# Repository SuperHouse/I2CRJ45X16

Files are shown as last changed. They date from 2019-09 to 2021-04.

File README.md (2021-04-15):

I2C to RJ45 Breakout (16 Port)
==============================
Copyright 2019-2021 SuperHouse Automation Pty Ltd  www.superhouse.tv  

24 RJ45 sockets connected to 64 I/O channels via I2C addressable
I/O controllers. Intended for use in building a home automation light
switch controller for connection to SuperHouse light switches.

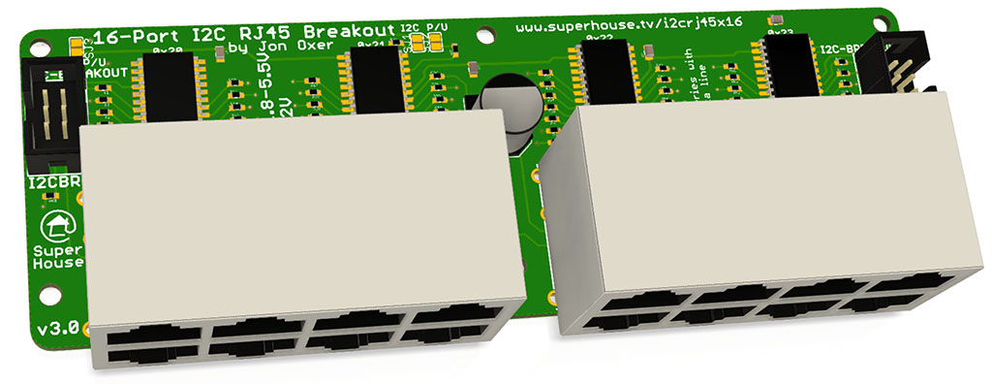
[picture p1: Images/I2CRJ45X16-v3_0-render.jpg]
I2C RJ45 Breakout PCB


Features:

 * 16 x RJ45 sockets for connection to light switches over Cat-5
 * I2C interface with interrupt output

This project has different versions:

 * 8-port version: https://github.com/superhouse/i2crj45x8
 * 16-port version: https://github.com/superhouse/i2crj45x16
 * 24-port version: https://github.com/superhouse/i2crj45x24
 * 24-port version with passthrough: https://github.com/superhouse/i2crj45x24pt

More information:

  http://www.superhouse.tv/i2crj45x16

INSTALLATION
------------
The design is saved as an EAGLE project. EAGLE PCB design software is
available from www.cadsoftusa.com free for non-commercial use. To use
this project download it and place the directory containing these files
into the "eagle" directory on your computer. Then open EAGLE and
navigate to the project.

CREDITS
-------
Designed by Jonathan Oxer jon@oxer.com.au

DISTRIBUTION
------------
The specific terms of distribution of this project are governed by the
license referenced below.

LICENSE
-------
Licensed under the TAPR Open Hardware License (www.tapr.org/OHL).
The "license" folder within this repository also contains a copy of
this license in plain text format.

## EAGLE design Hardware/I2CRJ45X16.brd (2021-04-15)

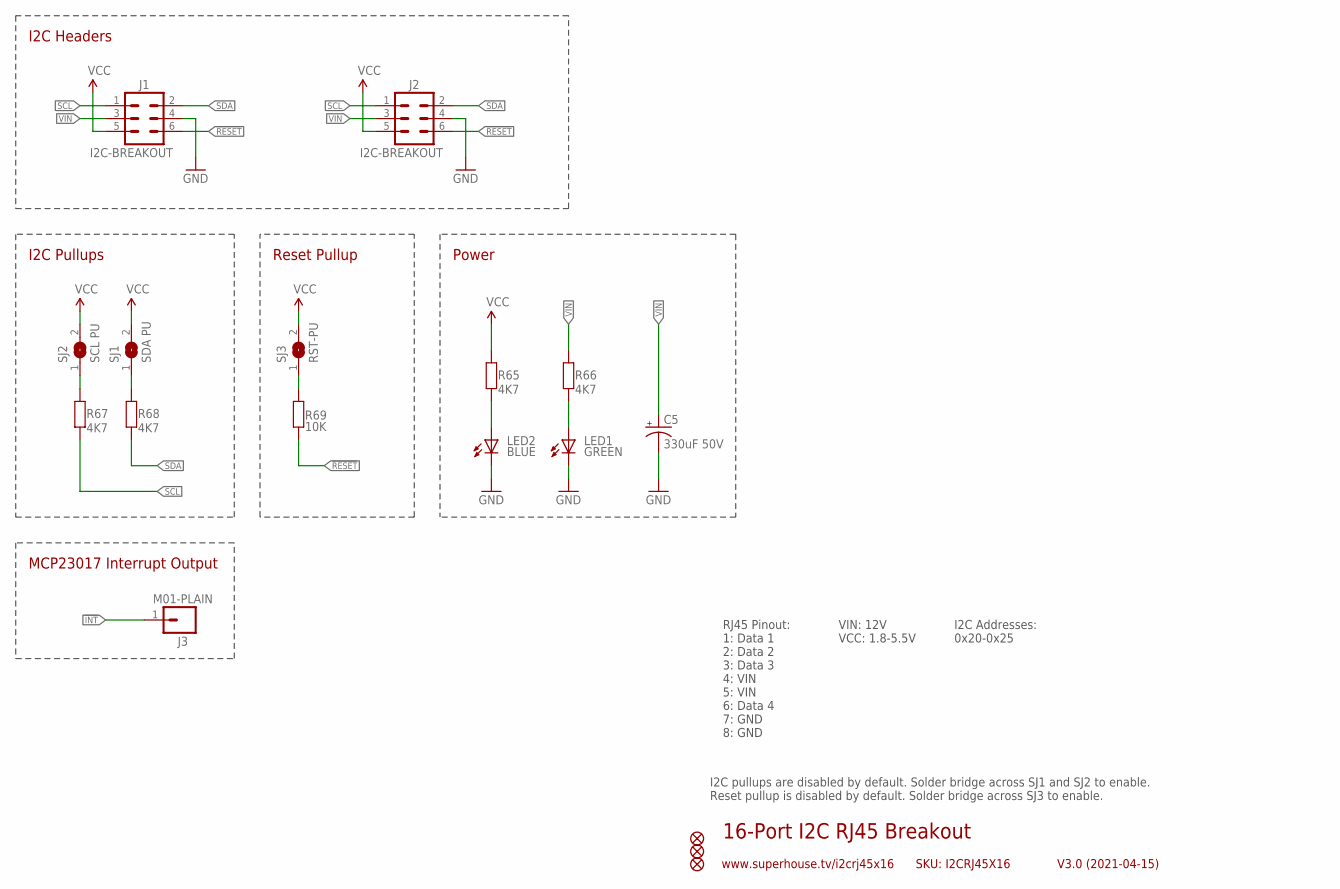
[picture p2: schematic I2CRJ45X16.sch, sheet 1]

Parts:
C5: 330uF 50V; PANASONIC_G
FID1, FID2, FID3: FIDUCIAL1X2.5; FIDUCIAL-1X2.5
J1, J2: I2C-BREAKOUT; 2X03-SHROUDED
J3: M01-PLAIN; 1X01
LED1: GREEN; LED-0603
LED2: BLUE; LED-0603
R65, R66, R67, R68: 4K7; R0603
R69: 10K; R0603
SJ1: SDA PU; SJ
SJ2: SCL PU; SJ
SJ3: RST-PU; SJ

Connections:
!INT: J3.1; also elsewhere on the board
!RESET: J1.6, J2.6, R69.1; also elsewhere on the board
GND: C5.-, J1.4, J2.4, LED1.C, LED2.C; also elsewhere on the board
unnamed: R67.2, SJ2.1
unnamed: R68.2, SJ1.1
unnamed: R69.2, SJ3.1
unnamed: LED2.A, R65.1
unnamed: LED1.A, R66.1
SCL: J1.1, J2.1, R67.1; also elsewhere on the board
SDA: J1.2, J2.2, R68.1; also elsewhere on the board
VCC: J1.5, J2.5, R65.2, SJ1.2, SJ2.2, SJ3.2; also elsewhere on the board
VIN: C5.+, J1.3, J2.3, R66.2; also elsewhere on the board

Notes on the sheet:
16-Port I2C RJ45 Breakout
V3.0 (2021-04-15)
www.superhouse.tv/i2crj45x16
SKU: I2CRJ45X16
RJ45 Pinout: 1: Data 1 2: Data 2 3: Data 3 4: VIN 5: VIN 6: Data 4 7: GND 8: GND
VIN: 12V VCC: 1.8-5.5V
I2C Addresses: 0x20-0x25
I2C Headers
MCP23017 Interrupt Output
I2C Pullups
I2C pullups are disabled by default. Solder bridge across SJ1 and SJ2 to enable. Reset pullup is disabled by default. Solder bridge across SJ3 to enable.
Power
Reset Pullup

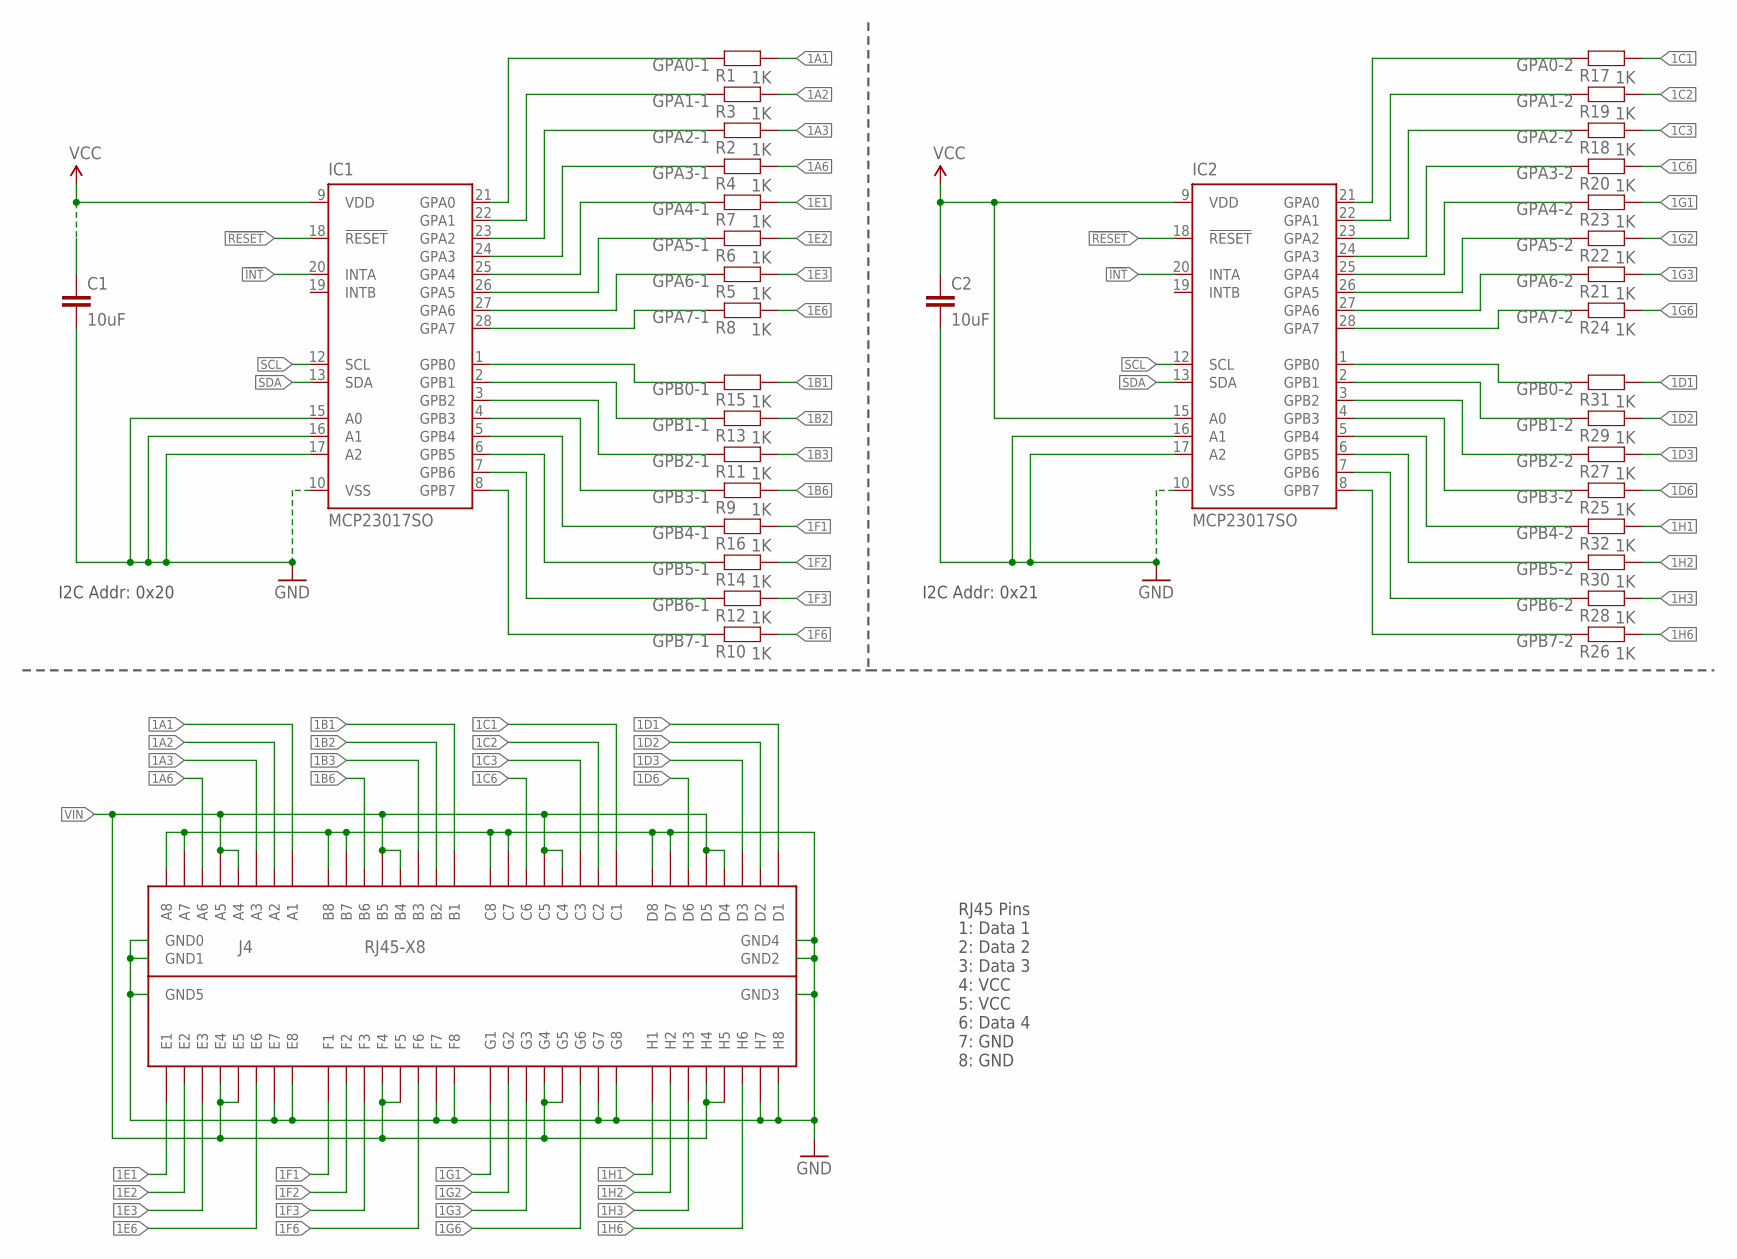
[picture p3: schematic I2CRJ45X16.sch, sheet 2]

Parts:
C1, C2: 10uF; C0805
IC1, IC2: MCP23017SO; SO28W
J4: RJ45-X8; RJ45-2X4
R1, R2, R3, R4, R5, R6, R7, R8, R9, R10, R11, R12, R13, R14, R15, R16, R17, R18, R19, R20, R21, R22, R23, R24, R25, R26, R27, R28, R29, R30, R31, R32: 1K; R0603

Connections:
1A1: J4.A1, R1.2
1A2: J4.A2, R3.2
1A3: J4.A3, R2.2
1A6: J4.A6, R4.2
1B1: J4.B1, R15.2
1B2: J4.B2, R13.2
1B3: J4.B3, R11.2
1B6: J4.B6, R9.2
1C1: J4.C1, R17.2
1C2: J4.C2, R19.2
1C3: J4.C3, R18.2
1C6: J4.C6, R20.2
1D1: J4.D1, R31.2
1D2: J4.D2, R29.2
1D3: J4.D3, R27.2
1D6: J4.D6, R25.2
1E1: J4.E1, R7.2
1E2: J4.E2, R6.2
1E3: J4.E3, R5.2
1E6: J4.E6, R8.2
1F1: J4.F1, R16.2
1F2: J4.F2, R14.2
1F3: J4.F3, R12.2
1F6: J4.F6, R10.2
1G1: J4.G1, R23.2
1G2: J4.G2, R22.2
1G3: J4.G3, R21.2
1G6: J4.G6, R24.2
1H1: J4.H1, R32.2
1H2: J4.H2, R30.2
1H3: J4.H3, R28.2
1H6: J4.H6, R26.2
!INT: IC1.20 (INTA), IC2.20 (INTA); also elsewhere on the board
!RESET: IC1.18 (!RESET), IC2.18 (!RESET); also elsewhere on the board
GND: C1.2, C2.2, IC1.10 (VSS), IC1.15 (A0), IC1.16 (A1), IC1.17 (A2), IC2.10 (VSS), IC2.16 (A1), IC2.17 (A2), J4.A7, J4.A8, J4.B7, J4.B8, J4.C7, J4.C8, J4.D7, J4.D8, J4.E7, J4.E8, J4.F7, J4.F8, J4.G7, J4.G8, J4.GND0, J4.GND1, J4.GND2, J4.GND3, J4.GND4, J4.GND5, J4.H7, J4.H8; also elsewhere on the board
GPA0-1: IC1.21 (GPA0), R1.1
GPA0-2: IC2.21 (GPA0), R17.1
GPA1-1: IC1.22 (GPA1), R3.1
GPA1-2: IC2.22 (GPA1), R19.1
GPA2-1: IC1.23 (GPA2), R2.1
GPA2-2: IC2.23 (GPA2), R18.1
GPA3-1: IC1.24 (GPA3), R4.1
GPA3-2: IC2.24 (GPA3), R20.1
GPA4-1: IC1.25 (GPA4), R7.1
GPA4-2: IC2.25 (GPA4), R23.1
GPA5-1: IC1.26 (GPA5), R6.1
GPA5-2: IC2.26 (GPA5), R22.1
GPA6-1: IC1.27 (GPA6), R5.1
GPA6-2: IC2.27 (GPA6), R21.1
GPA7-1: IC1.28 (GPA7), R8.1
GPA7-2: IC2.28 (GPA7), R24.1
GPB0-1: IC1.1 (GPB0), R15.1
GPB0-2: IC2.1 (GPB0), R31.1
GPB1-1: IC1.2 (GPB1), R13.1
GPB1-2: IC2.2 (GPB1), R29.1
GPB2-1: IC1.3 (GPB2), R11.1
GPB2-2: IC2.3 (GPB2), R27.1
GPB3-1: IC1.4 (GPB3), R9.1
GPB3-2: IC2.4 (GPB3), R25.1
GPB4-1: IC1.5 (GPB4), R16.1
GPB4-2: IC2.5 (GPB4), R32.1
GPB5-1: IC1.6 (GPB5), R14.1
GPB5-2: IC2.6 (GPB5), R30.1
GPB6-1: IC1.7 (GPB6), R12.1
GPB6-2: IC2.7 (GPB6), R28.1
GPB7-1: IC1.8 (GPB7), R10.1
GPB7-2: IC2.8 (GPB7), R26.1
SCL: IC1.12 (SCL), IC2.12 (SCL); also elsewhere on the board
SDA: IC1.13 (SDA), IC2.13 (SDA); also elsewhere on the board
VCC: C1.1, C2.1, IC1.9 (VDD), IC2.9 (VDD), IC2.15 (A0); also elsewhere on the board
VIN: J4.A4, J4.A5, J4.B4, J4.B5, J4.C4, J4.C5, J4.D4, J4.D5, J4.E4, J4.E5, J4.F4, J4.F5, J4.G4, J4.G5, J4.H4, J4.H5; also elsewhere on the board

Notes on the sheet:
RJ45 Pins 1: Data 1 2: Data 2 3: Data 3 4: VCC 5: VCC 6: Data 4 7: GND 8: GND
I2C Addr: 0x20
I2C Addr: 0x21

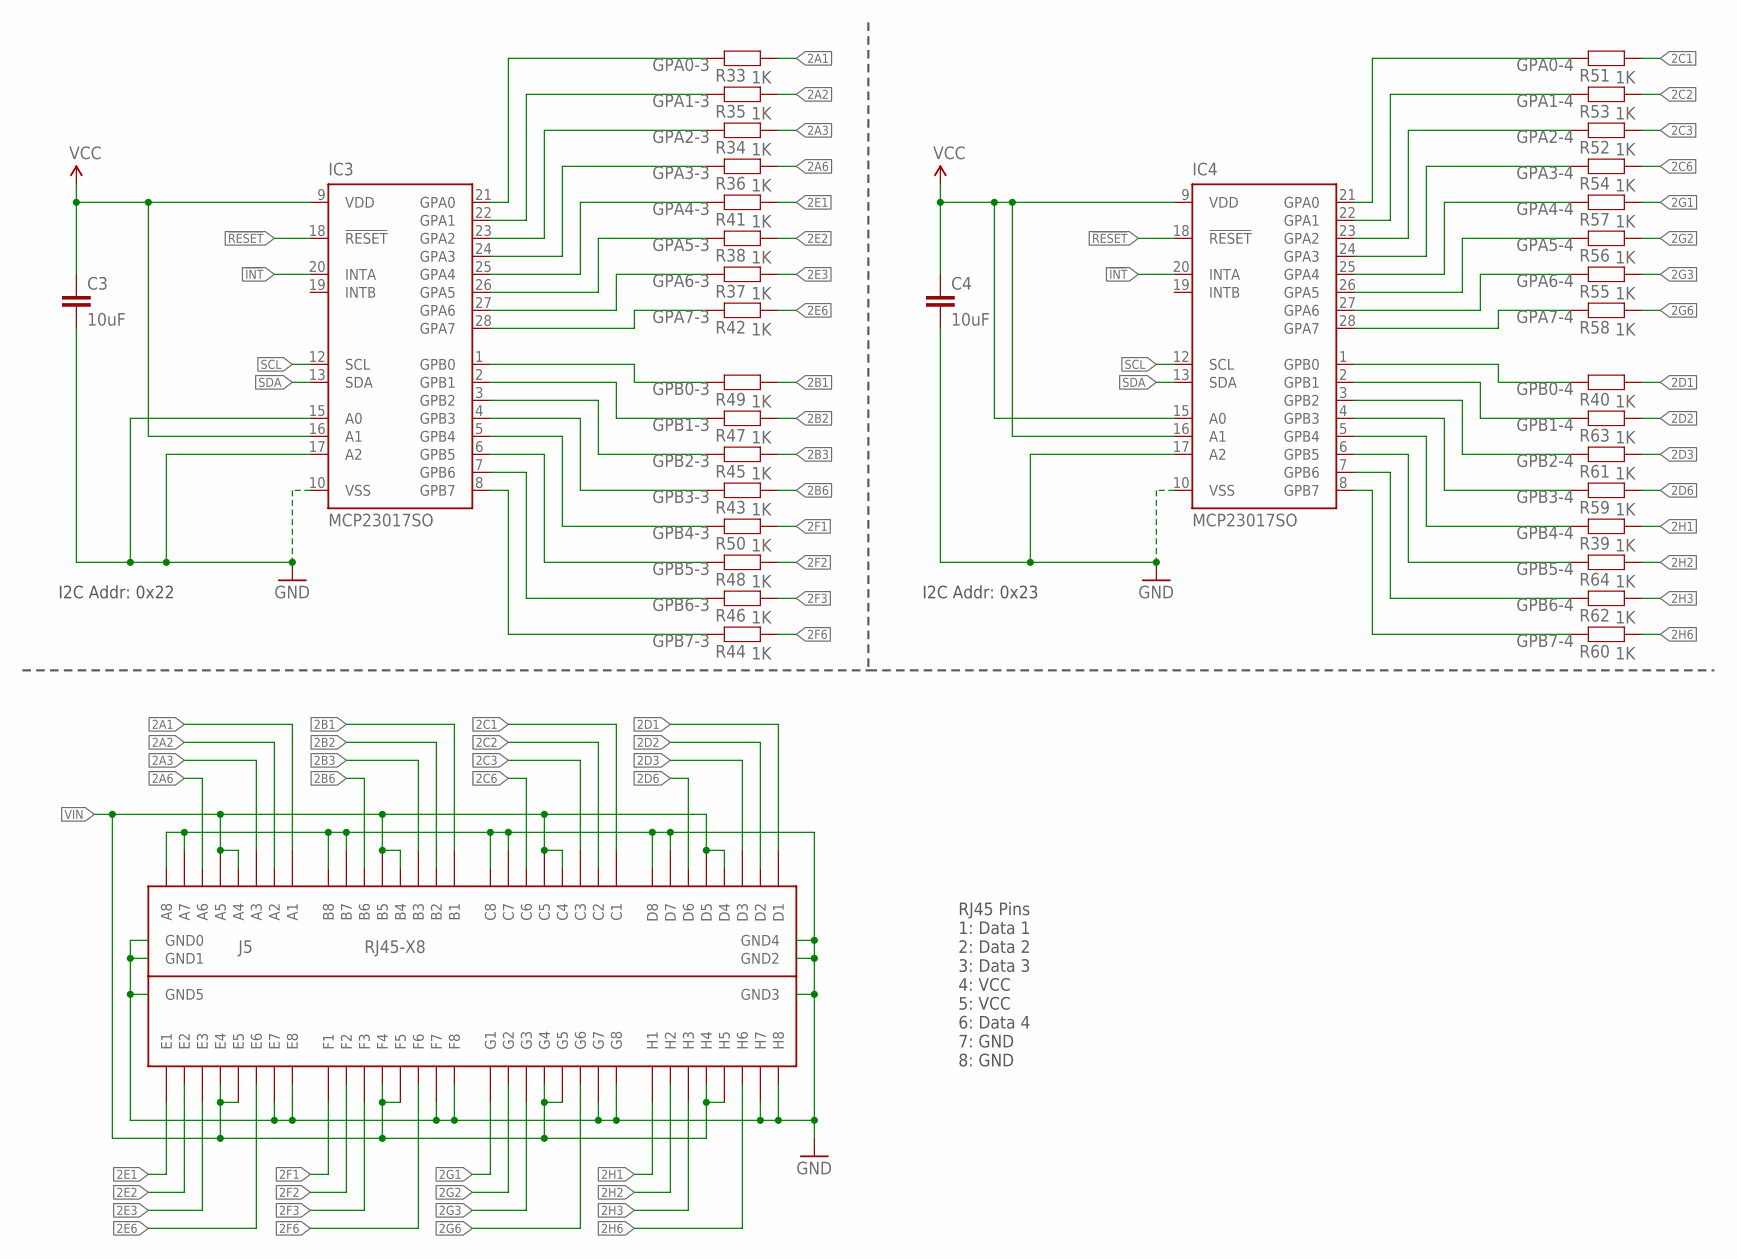
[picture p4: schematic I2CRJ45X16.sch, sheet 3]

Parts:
C3, C4: 10uF; C0805
IC3, IC4: MCP23017SO; SO28W
J5: RJ45-X8; RJ45-2X4
R33, R34, R35, R36, R37, R38, R39, R40, R41, R42, R43, R44, R45, R46, R47, R48, R49, R50, R51, R52, R53, R54, R55, R56, R57, R58, R59, R60, R61, R62, R63, R64: 1K; R0603

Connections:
2A1: J5.A1, R33.2
2A2: J5.A2, R35.2
2A3: J5.A3, R34.2
2A6: J5.A6, R36.2
2B1: J5.B1, R49.2
2B2: J5.B2, R47.2
2B3: J5.B3, R45.2
2B6: J5.B6, R43.2
2C1: J5.C1, R51.2
2C2: J5.C2, R53.2
2C3: J5.C3, R52.2
2C6: J5.C6, R54.2
2D1: J5.D1, R40.2
2D2: J5.D2, R63.2
2D3: J5.D3, R61.2
2D6: J5.D6, R59.2
2E1: J5.E1, R41.2
2E2: J5.E2, R38.2
2E3: J5.E3, R37.2
2E6: J5.E6, R42.2
2F1: J5.F1, R50.2
2F2: J5.F2, R48.2
2F3: J5.F3, R46.2
2F6: J5.F6, R44.2
2G1: J5.G1, R57.2
2G2: J5.G2, R56.2
2G3: J5.G3, R55.2
2G6: J5.G6, R58.2
2H1: J5.H1, R39.2
2H2: J5.H2, R64.2
2H3: J5.H3, R62.2
2H6: J5.H6, R60.2
!INT: IC3.20 (INTA), IC4.20 (INTA); also elsewhere on the board
!RESET: IC3.18 (!RESET), IC4.18 (!RESET); also elsewhere on the board
GND: C3.2, C4.2, IC3.10 (VSS), IC3.15 (A0), IC3.17 (A2), IC4.10 (VSS), IC4.17 (A2), J5.A7, J5.A8, J5.B7, J5.B8, J5.C7, J5.C8, J5.D7, J5.D8, J5.E7, J5.E8, J5.F7, J5.F8, J5.G7, J5.G8, J5.GND0, J5.GND1, J5.GND2, J5.GND3, J5.GND4, J5.GND5, J5.H7, J5.H8; also elsewhere on the board
GPA0-3: IC3.21 (GPA0), R33.1
GPA0-4: IC4.21 (GPA0), R51.1
GPA1-3: IC3.22 (GPA1), R35.1
GPA1-4: IC4.22 (GPA1), R53.1
GPA2-3: IC3.23 (GPA2), R34.1
GPA2-4: IC4.23 (GPA2), R52.1
GPA3-3: IC3.24 (GPA3), R36.1
GPA3-4: IC4.24 (GPA3), R54.1
GPA4-3: IC3.25 (GPA4), R41.1
GPA4-4: IC4.25 (GPA4), R57.1
GPA5-3: IC3.26 (GPA5), R38.1
GPA5-4: IC4.26 (GPA5), R56.1
GPA6-3: IC3.27 (GPA6), R37.1
GPA6-4: IC4.27 (GPA6), R55.1
GPA7-3: IC3.28 (GPA7), R42.1
GPA7-4: IC4.28 (GPA7), R58.1
GPB0-3: IC3.1 (GPB0), R49.1
GPB0-4: IC4.1 (GPB0), R40.1
GPB1-3: IC3.2 (GPB1), R47.1
GPB1-4: IC4.2 (GPB1), R63.1
GPB2-3: IC3.3 (GPB2), R45.1
GPB2-4: IC4.3 (GPB2), R61.1
GPB3-3: IC3.4 (GPB3), R43.1
GPB3-4: IC4.4 (GPB3), R59.1
GPB4-3: IC3.5 (GPB4), R50.1
GPB4-4: IC4.5 (GPB4), R39.1
GPB5-3: IC3.6 (GPB5), R48.1
GPB5-4: IC4.6 (GPB5), R64.1
GPB6-3: IC3.7 (GPB6), R46.1
GPB6-4: IC4.7 (GPB6), R62.1
GPB7-3: IC3.8 (GPB7), R44.1
GPB7-4: IC4.8 (GPB7), R60.1
SCL: IC3.12 (SCL), IC4.12 (SCL); also elsewhere on the board
SDA: IC3.13 (SDA), IC4.13 (SDA); also elsewhere on the board
VCC: C3.1, C4.1, IC3.9 (VDD), IC3.16 (A1), IC4.9 (VDD), IC4.15 (A0), IC4.16 (A1); also elsewhere on the board
VIN: J5.A4, J5.A5, J5.B4, J5.B5, J5.C4, J5.C5, J5.D4, J5.D5, J5.E4, J5.E5, J5.F4, J5.F5, J5.G4, J5.G5, J5.H4, J5.H5; also elsewhere on the board

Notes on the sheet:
RJ45 Pins 1: Data 1 2: Data 2 3: Data 3 4: VCC 5: VCC 6: Data 4 7: GND 8: GND
I2C Addr: 0x22
I2C Addr: 0x23

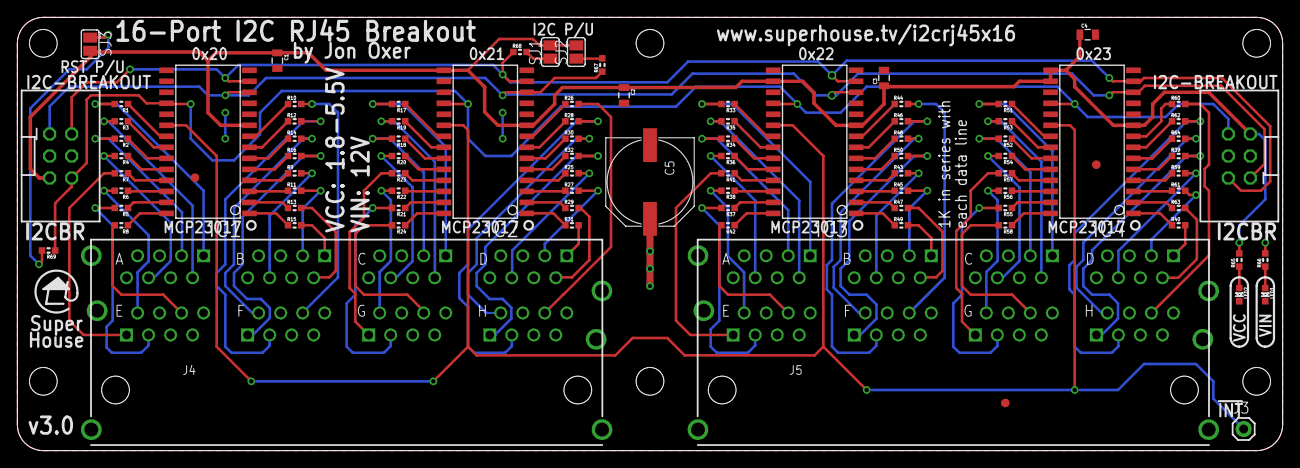
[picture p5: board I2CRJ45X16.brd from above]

Board: 2 copper layers, 146.0 x 50.0 mm, 91 parts (0 on the bottom side), 140 nets.

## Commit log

2019-08-15 Renamed files for v1.0 release
    [I2C16RJ45.brd, I2C16RJ45.sch]
2019-09-07 Board and schematic labelling
    [I2C16RJ45.brd, I2C16RJ45.sch]
2019-09-07 Added fiducials
    [I2C16RJ45.brd, I2C16RJ45.sch]
2021-04-12 Moved hardware files into subdirectory.
    [I2C16RJ45.brd, I2C16RJ45.sch]
2021-04-15 Renamed existing project files.
    [I2CRJ45X16-old.brd, I2CRJ45X16-old.sch]
2021-04-15 Replaced project files with major redesign for v3.0 release.
    [I2CRJ45X16.brd, I2CRJ45X16.sch]
2021-04-15 Major rework based on 24-port version.
    [I2CRJ45X16.brd, I2CRJ45X16.sch]

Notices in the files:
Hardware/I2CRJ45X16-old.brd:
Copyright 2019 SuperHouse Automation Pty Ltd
